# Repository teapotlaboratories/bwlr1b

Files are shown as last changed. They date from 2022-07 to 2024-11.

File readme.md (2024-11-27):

  
  
# Teapot BWLR1B
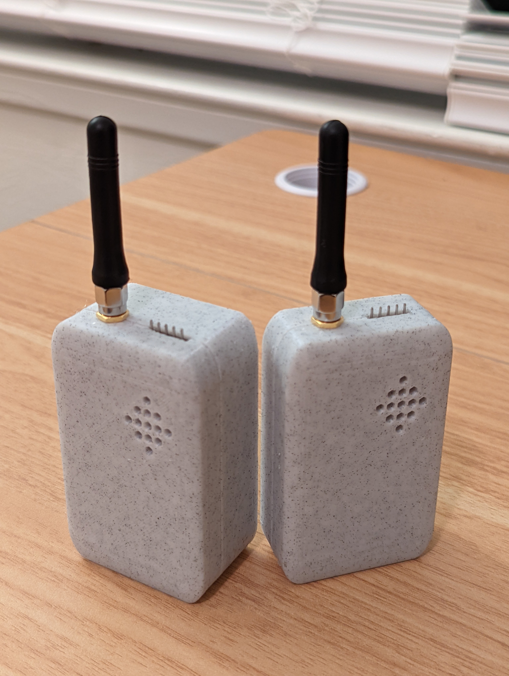
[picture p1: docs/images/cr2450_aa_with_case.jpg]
 
 
Teapot BWLR1B is a wireless LoRa environmental sensor capable of sensing temperature, humidity, air pressure and air quality using the on-board BME680. 
By using an STM32WLE MCU, the device is capable of multi-year operation before changing the batteries

Teapot BWLR1B is part of  [Teapot open-hardware project](https://github.com/teapotlaboratories). 

## Sponsorship
We sincerely thank [PCBWay](https://www.pcbway.com/) for their sponsorship and support. Their high-quality rapid-prototyping services, including PCB Board manufacturing, PCB Assembly, and 3D Printing, have been a great asset to our work.
We truly appreciate their attention to detail in helping us:
  - Identify design issues
  - Verify our BOM (Bill of Materials)
  - Verify the final product after assembly

On top of their technical expertise, their customer support has been responsive, and easy to work with.

## Disclaimer
- The 1KM+ range have not been verified yet
- The position of the BME680 sensor on the board might not be the most efficient 

## Future Works
- Change `SW4` wiring from GND to 3V3, to allow booting to STM32WLE USART Bootloader. This enable the user to flash the RAK3172 module using STM32CubeProgrammer without ST-Link.

## Specification

- [RAK3172](https://docs.rakwireless.com/Product-Categories/WisDuo/RAK3172-Module/Overview/): An STM32WLE5CC module
- 3.3V only power/pin. 
- 2uA Deep-Sleep
- BME680 for Environmental Sensing
- Switchable TX Power. 14 dBm(50mA) or 22 dBm(140mA) ( on 915MHz frequency )
- Supports LoRaWAN 1.0.3
- 1KM+ Range
- UART2 breakout for **Arduino** progamming
- SWD breakout for **Mbed OS/STM32Cube** programming
- SMA antenna connector
- **CR2450** battery holder *xor* **AA** battery holder
- Capacitor ( [optional to prolong CR2450 usage](https://www.rs-online.com/designspark/can-i-prolong-my-coin-cell-battery-life-with-a-capacitor) )

> Based-on [TI's White Paper](https://www.ti.com/lit/wp/swra349/swra349.pdf), using coin-cell to draw short high-power pulses (~40mA) is possible, but will reduce the effective capacity of the battery. The White Paper proposed a solution to increase the effective capacity
## Schematics

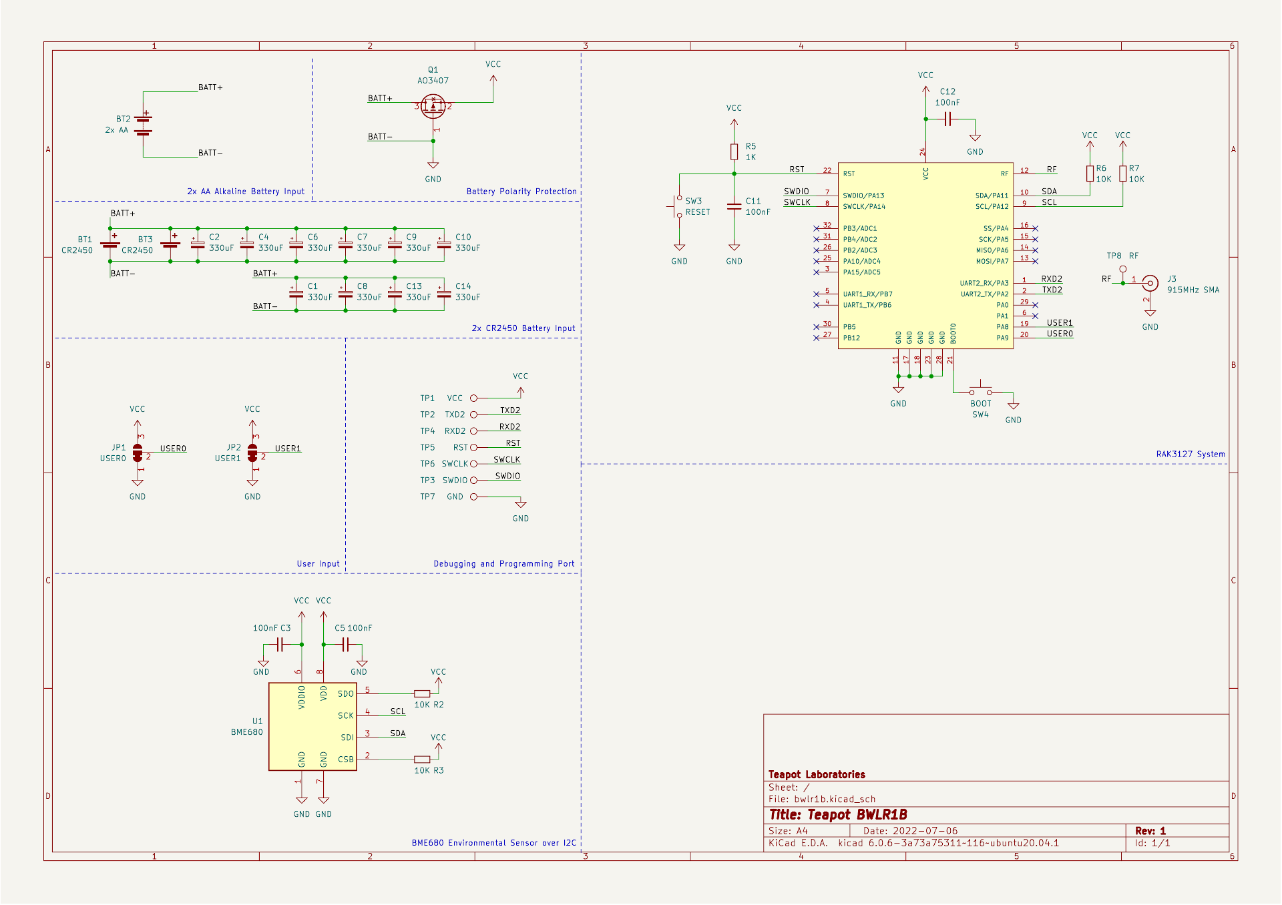
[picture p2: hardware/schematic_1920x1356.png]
schematic


## Boards 
 

Built using KiCAD v6, the board is design to be as small as possible when operated using CR2450 coin-cell batteries

### Design
The device designed to be operable using **2x CR2450** coin cell batteries *xor* the standard **2x AA** batteries.
By using the RAK3172 module, it is possible to use the IPEX [variant](https://store.rakwireless.com/products/wisduo-lpwan-module-rak3172?variant=40014759297222) of the module and use a [PCB antenna](https://store.rakwireless.com/products/pcb-antenna-for-lora) connected to the IPEX port on the RAK3172 module.
| Top Board | Bottom Board with AA or CR2450 Battery |
|--|--|
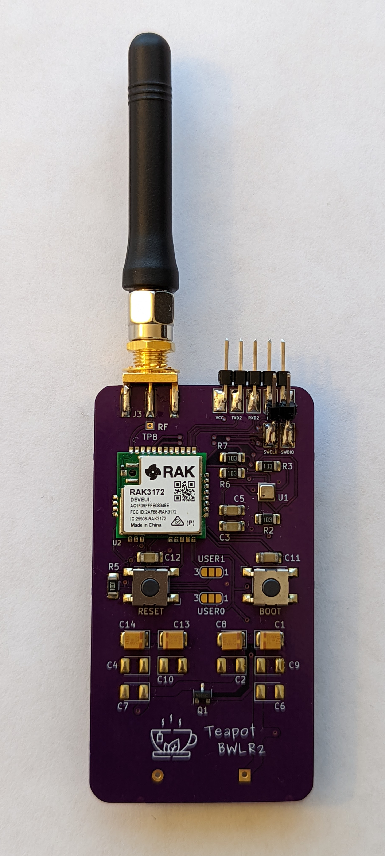
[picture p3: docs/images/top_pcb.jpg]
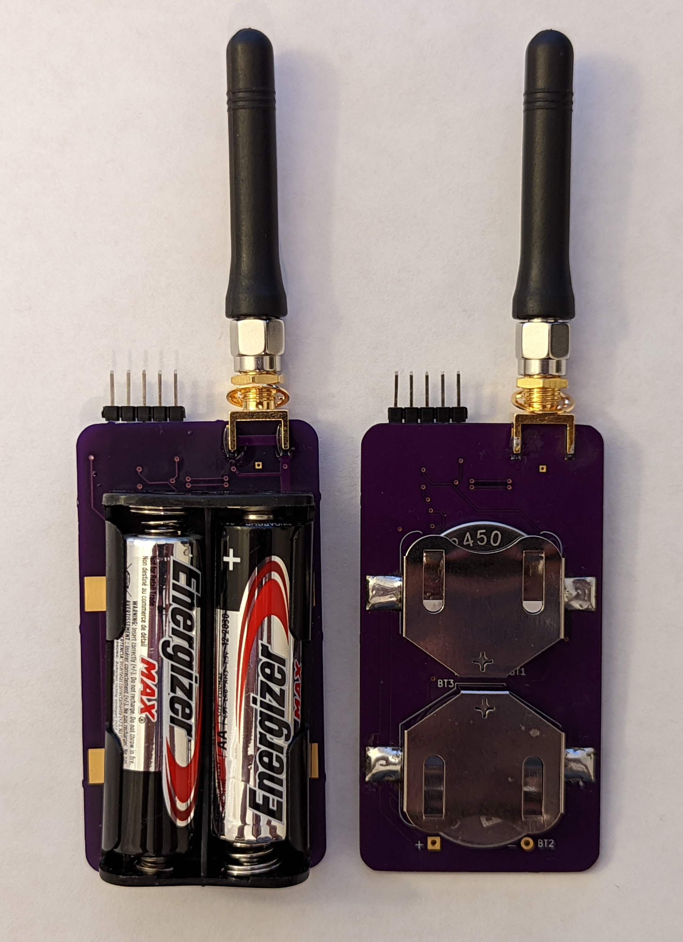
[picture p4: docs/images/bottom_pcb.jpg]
|  |  |
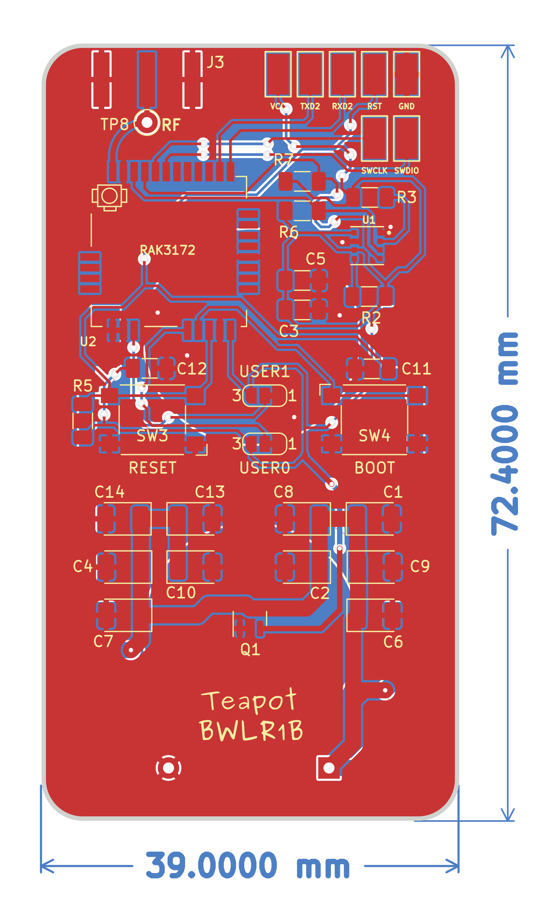
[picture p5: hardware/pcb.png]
   
  
### Case
 The cases are available for the CR2450 variant and the AA variant, 3D printable with any generic 3D printer with/without suppport (depends on the orientation). The STL files are available [here](https://github.com/teapotlaboratories/bwlr1b/tree/master/hardware/case)
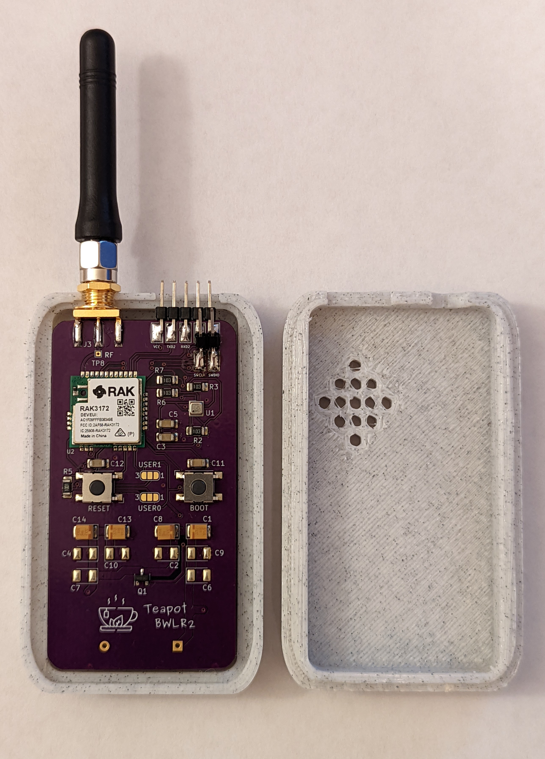
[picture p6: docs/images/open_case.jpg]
  

### Measurement
Power consumption and solar charging current are measured using [Nordic PPK2](https://www.nordicsemi.com/Products/Development-hardware/Power-Profiler-Kit-2).
The following are the summary of the measurement:
- Transmit 14dBm:  446ms @ 43mA
- Deep-Sleep : 2 uA

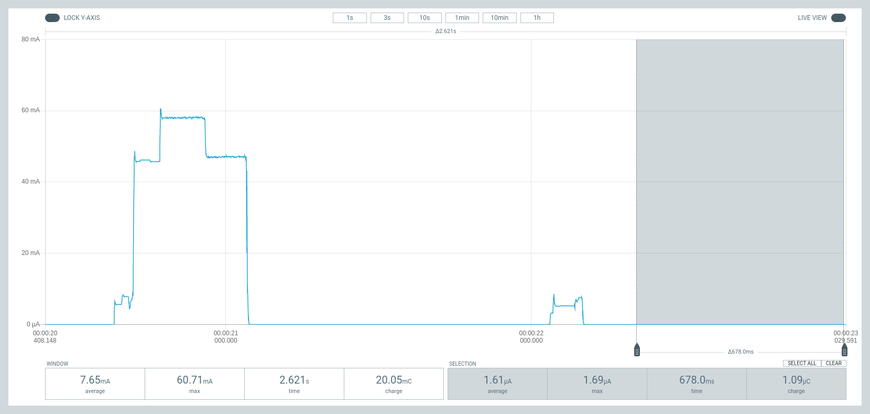
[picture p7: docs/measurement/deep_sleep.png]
deep_sleep
<p align="center"><br><b>Deep-Sleep</b></p>

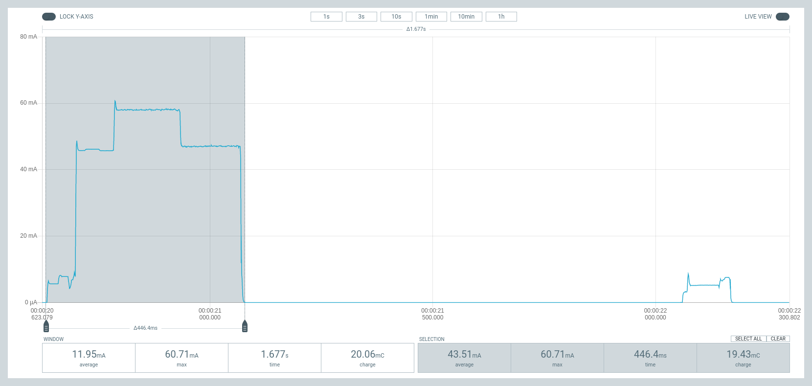
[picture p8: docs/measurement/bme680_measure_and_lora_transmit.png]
bme688_measure_and_lora_transmit
<p align="center"><br><b>BME688 Measure and LoRa Transmit</b></p>

More measurement can be found [here](https://github.com/teapotlaboratories/bwlr1b/tree/main/docs/measurement)
 
### Bill Of Materials
Most of the components are generic and can be bought from any electornics/semi-conductor distributor. RAK3172 is the only component available in [RAKwireless store.](https://store.rakwireless.com/products/wisduo-lpwan-module-rak3172?variant=40014759493830). The bill of materials can be downloaded [here](https://raw.githubusercontent.com/teapotlaboratories/bwlr1b/master/hardware/bill_of_materials.csv)

> :warning: **Be sure to buy the RAK3172 variant without IPEX to use the SMA connector** 

|Id |Designator |Package |Quantity|Designation|Supplier and ref|Notes |
|---|---|---|---|---|---|---|
|1  |BT2 |BatteryHolder_Keystone_2462_2xAA |1 |2x AA | |Mutual Exclusive with BT3 and BT1|
|2  |BT3,BT1 |BatteryHolder_Keystone_3008_1x2450 |2 |CR2450 | |Mutual Exclusive with BT2 |
|3  |C5,C12,C11,C3 |C_1206_3216Metric_Pad1.33x1.80mm_HandSolder |4 |100nF | | |
|4  |C9,C8,C10,C2,C4,C13,C14,C6,C1,C7|CP_EIA-3528-15_AVX-H_Pad1.50x2.35mm_HandSolder|10 |330uF | |Optional |
|5  |J3 |SMA_Amphenol_132289_EdgeMount |1 |915MHz SMA | | |
|6  |Q1 |SOT-23 |1 |AO3407 | | |
|7  |R5 |R_1206_3216Metric_Pad1.30x1.75mm_HandSolder |1 |1K | | |
|8  |R7,R2,R3,R6 |R_1206_3216Metric_Pad1.30x1.75mm_HandSolder |4 |10K | | |
|9  |SW3 |SW_SPST_Omron_B3FS-100xP |1 |RESET | | |
|10 |SW4 |SW_SPST_Omron_B3FS-100xP |1 |BOOT | | |
|11 |U1 |BME680-PSON80P300X300X100-8N |1 |BME680 | | |
|12 |U2 |RAK3172 without IPEX |1 |RAK3172 |RAKwireless | |

## Programming
Programming the device can be done over the **UART2** or **SWD**, available next to the SMA antenna port.
Out of the factory, the RAK3172 chip ships with an **AT firmware** that can be tested by connecting a USB-to-UART bridge to the **UART2** port.

The following are some very good tutorial to start developing with the device:

- [Communicating with the AT firmware](https://docs.rakwireless.com/Product-Categories/WisDuo/RAK3172-Module/Quickstart/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)
 - [Programming with Arduino](https://docs.rakwireless.com/Product-Categories/WisDuo/RAK3172-Module/Quickstart/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)
 - [Programming with STM32Cube](https://docs.rakwireless.com/Product-Categories/WisDuo/RAK3172-Module/Low-Level-Development/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)
 - [Programming with MbedOS](https://github.com/hallard/LoRa-E5-Tiny/blob/main/README.md#compile-and-flash-firmware)

For connecting to the **UART2** port, use any USB-to-UART bridge module. In testing, the [Sparkfun](https://www.sparkfun.com/products/14050) board is used for communication with AT firmware and programming over **Arduino**.
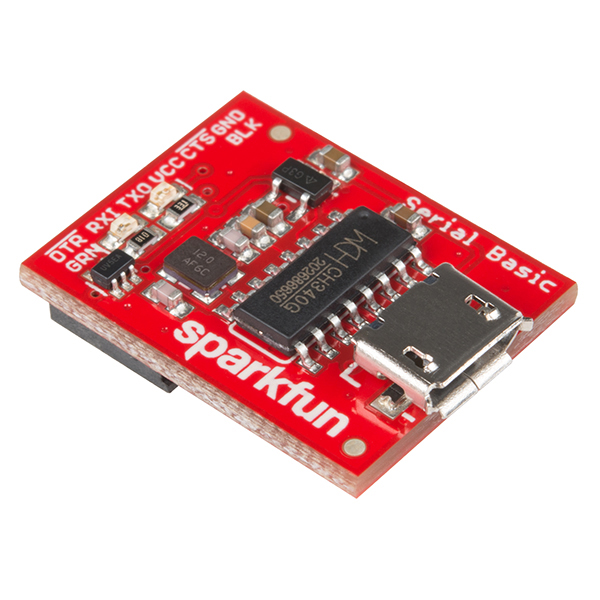
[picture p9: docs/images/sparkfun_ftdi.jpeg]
 <p align="center"> <br>Sparkfun USB-to-UART Bridge</p>

> :warning: **Be sure to only use 3.3V module. Do not 5V module** 

For connecting to the **SWD** port, use ST-Link v2  in-circuit debugger and programmer from STM. In testing, ST-Link v2 clone will not work. The ST-Link v2 should atleast be reconizeable by the [STM32CubeProgrammer](https://www.st.com/en/development-tools/stm32cubeprog.html).
A cheap and alternative way to get an authorized ST-Link is to buy a Nucleo board, cut the top part which contain the ST-Link and use it as an external programmer.
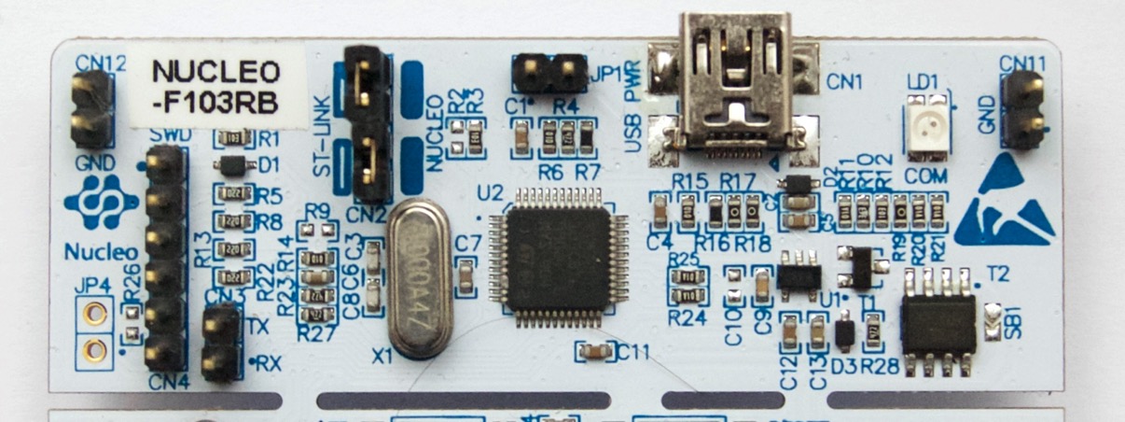
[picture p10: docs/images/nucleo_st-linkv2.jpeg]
 <p align="center"> <br>ST-Link v2 from a Nucleo Development Board</p>
Here are some good tutorial to convert a Nucleo to and external ST-Link v2:

 - https://www.radioshuttle.de/en/turtle-en/nucleo-st-link-interface-en/
 - https://jeelabs.org/book/1547a/index.html

## Reference
The project won't be possible without the amazing work from people across the globe. The following are the reference to those awesome projects:

 - [LoRa e5 Tiny](https://github.com/hallard/LoRa-E5-Tiny)
 - [AERQ - Air Quality Monitoring](https://www.seeedstudio.com/blog/2022/04/27/monitoring-indoor-air-pollutants-the-silent-issue-for-smart-city-iot-using-seeed-lora-e5-and-fusion-pcba/)

## License
The product is open-source! However, some part of library used under **src**, might have it's own license.
Please reach out or create a ticket to report any license violation.



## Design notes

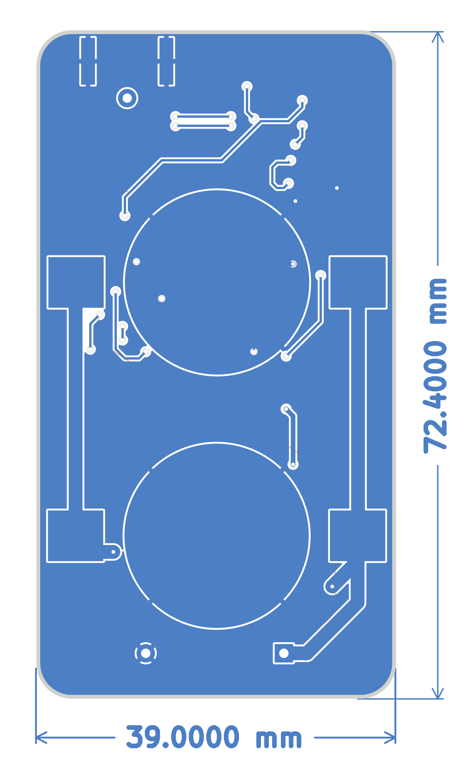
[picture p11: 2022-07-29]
hardware/pcb_bottom.png

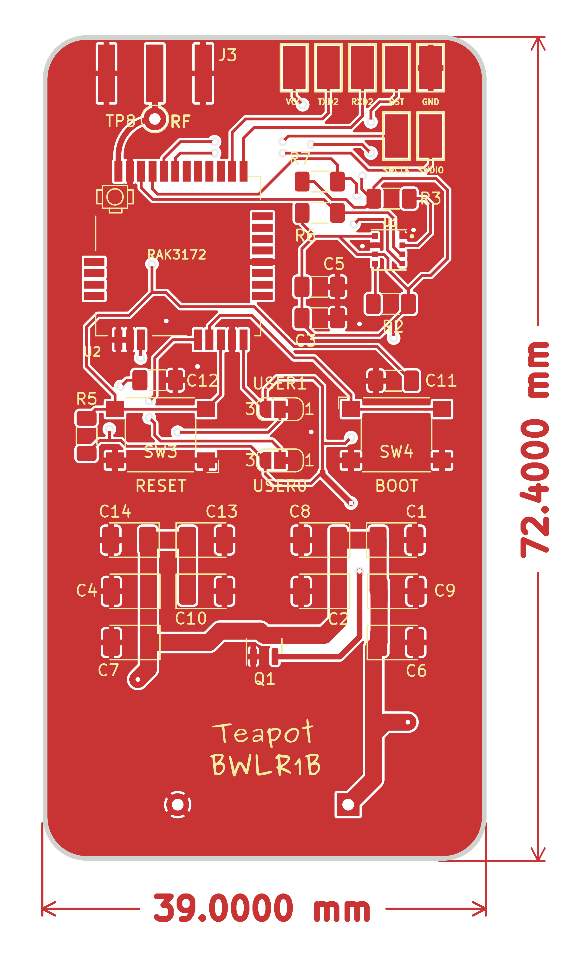
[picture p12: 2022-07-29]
hardware/pcb_top.png

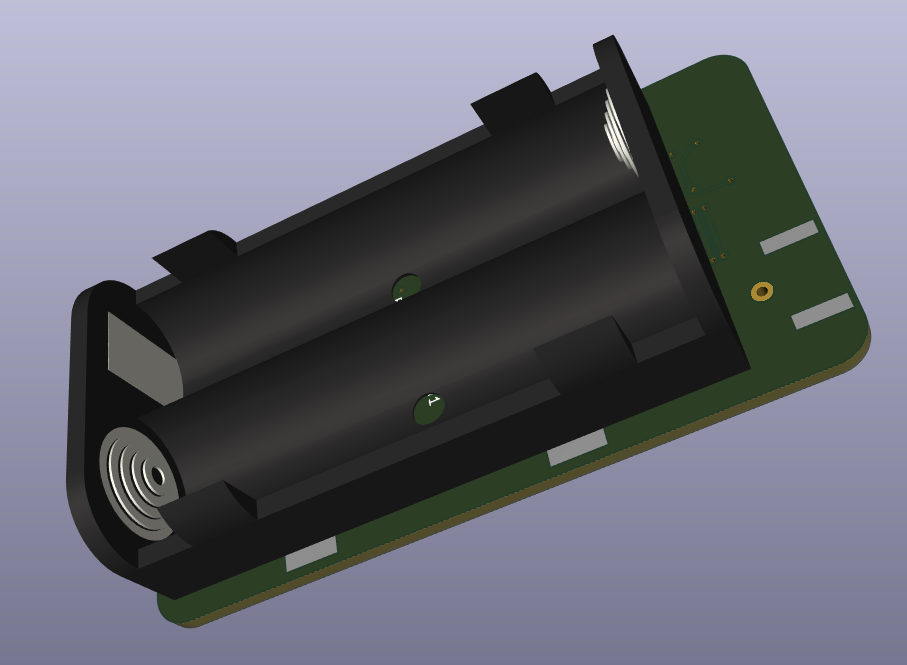
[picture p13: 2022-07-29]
docs/images/3d_bottom_aa.png

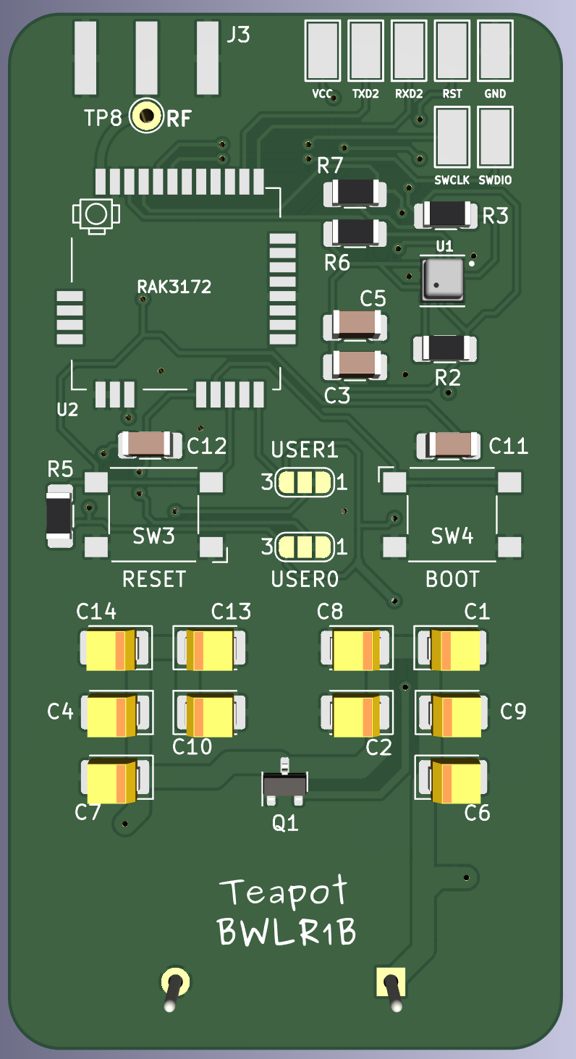
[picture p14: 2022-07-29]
docs/images/3d_top.png

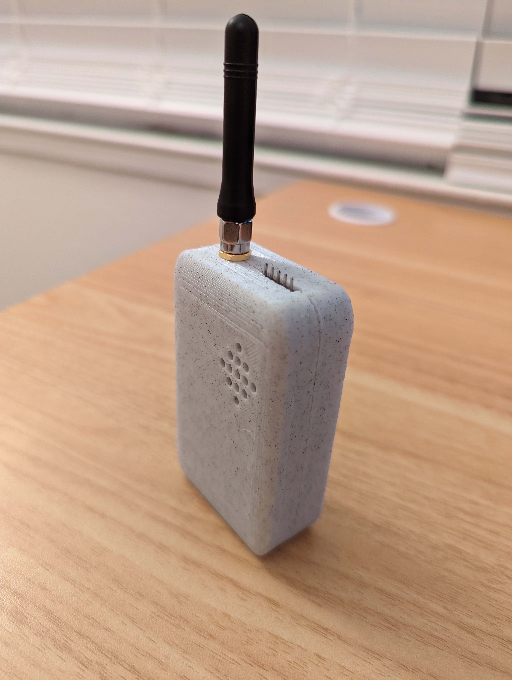
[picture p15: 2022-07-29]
docs/images/cr2450_with_case.jpg

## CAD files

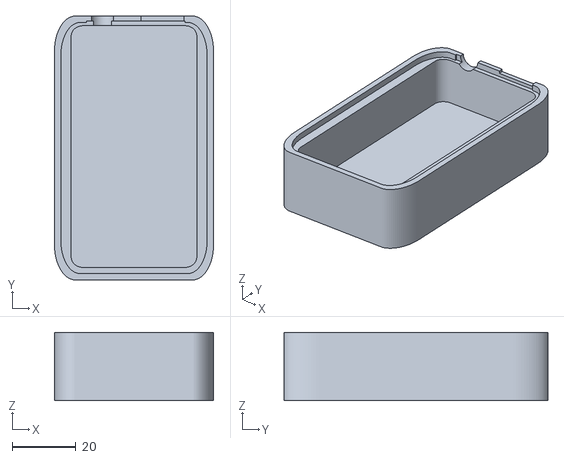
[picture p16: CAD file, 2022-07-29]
hardware/case/bottom_case_aa.stl
50.0 x 83.0 x 21.5

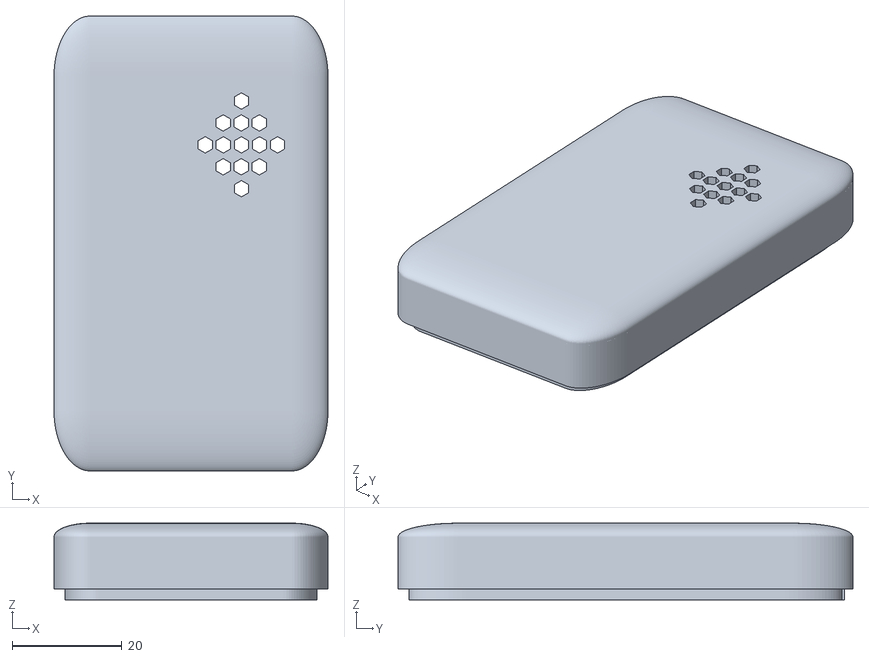
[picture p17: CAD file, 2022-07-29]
hardware/case/top_case.stl
50.0 x 83.0 x 14.0

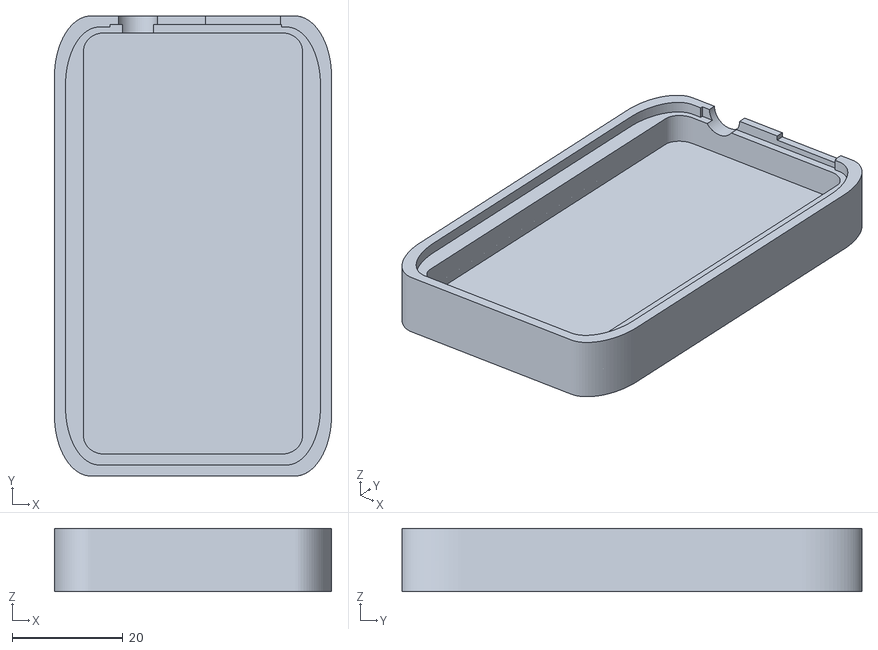
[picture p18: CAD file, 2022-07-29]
hardware/case/bottom_case_cr2450.stl
50.0 x 83.0 x 11.4

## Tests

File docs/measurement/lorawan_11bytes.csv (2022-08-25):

Timestamp(ms) | Current(uA)
0 | 1.512
1 | 1.502
2 | 1.505
3 | 1.501
4 | 1.505
5 | 1.497
6 | 1.482
7 | 1.502
8 | 1.486
9 | 1.482
10 | 1.491
11 | 1.494
12 | 1.487
13 | 1.499
14 | 1.496
15 | 1.494
16 | 1.487
17 | 1.488
18 | 1.484
19 | 1.492
20 | 1.496
21 | 1.498
22 | 1.496
23 | 1.502
24 | 1.492
25 | 1.496
26 | 1.494
27 | 1.500
28 | 1.501
29 | 1.493
30 | 1.491
31 | 1.495
32 | 1.499
33 | 1.490
34 | 1.498
35 | 1.497
36 | 1.507
37 | 1.501
38 | 1.493
39 | 1.497
40 | 1.498
41 | 1.495
42 | 1.496
43 | 1.506
44 | 1.507
45 | 1.499
46 | 1.500
47 | 1.496
48 | 1.504
49 | 1.493
50 | 1.506
51 | 1.501
52 | 1.522
53 | 1.542
54 | 1.537
55 | 1.542
56 | 1.535
57 | 1.547
58 | 1.542
59 | 1.542
60 | 1.533
61 | 1.519
62 | 1.525
63 | 1.526
64 | 1.523
65 | 1.519
66 | 1.516
67 | 1.525
68 | 1.528
69 | 1.522
70 | 1.530
71 | 1.530
72 | 1.525
73 | 1.519
74 | 1.514
75 | 1.511
76 | 1.508
77 | 1.500
78 | 1.504
79 | 1.506
80 | 1.509
81 | 1.500
82 | 1.506
83 | 1.506
84 | 1.507
85 | 1.512
86 | 1.515
87 | 1.511
88 | 1.501
89 | 1.509
90 | 1.504
91 | 1.514
92 | 1.512
93 | 1.512
94 | 1.506
95 | 1.509
96 | 1.500
97 | 1.512
98 | 1.509
99 | 1.507
100 | 1.503
101 | 1.499
102 | 1.494
103 | 1.500
104 | 1.500
105 | 1.506
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

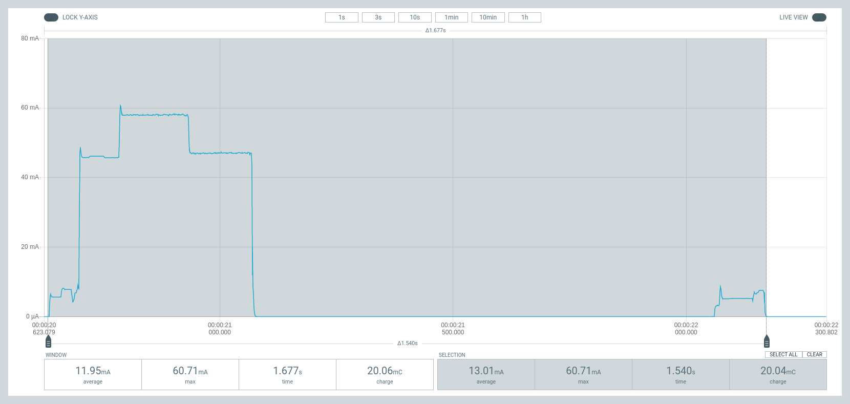
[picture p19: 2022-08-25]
docs/measurement/active.png

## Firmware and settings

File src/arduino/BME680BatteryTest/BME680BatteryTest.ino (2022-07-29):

/*! @file I2CDemo.ino

@section I2CDemo_intro_section Description

Example program for using I2C to set and read the Bosch BME680 sensor. The sensor measures
temperature, pressure and humidity and is described at
https://www.bosch-sensortec.com/bst/products/all_products/BME680. The datasheet is available from
Bosch at https://ae-bst.resource.bosch.com/media/_tech/media/datasheets/BST-BME680_DS001-11.pdf \n\n

The most recent version of the BME680 library is available at https://github.com/SV-Zanshin/BME680
and the documentation of the library as well as example programs are described in the project's wiki
pages located at https://github.com/SV-Zanshin/BME680/wiki. \n\n

The BME680 is an extremely small physical package that is so tiny as to be impossible to solder at
home, hence it will be used as part of a third-party breakout board. There are several such boards
available at this time, for example \n Company  | Link
-------  | ----------
Sparkfun | https://www.sparkfun.com/products/14570
BlueDot  | https://www.bluedot.space/sensor-boards/bme680/
Adafruit |
https://learn.adafruit.com/adafruit-BME680-humidity-barometric-pressure-temperature-sensor-breakout
\n\n

Bosch supplies sample software that runs on various platforms, including the Arduino family; this
can be downloaed at https://github.com/BoschSensortec/BSEC-Arduino-library . This software is part
of the Bosch "BSEC" (Bosch Sensortec Environmental Cluster) framework and somewhat bulky and
unwieldy for typical Arduino applications, hence the choice to make a more compact and rather less
abstract library.

This example program initializes the BME680 to use I2C for communications. The library does not
using floating point numbers to save on memory space and computation time. The values for
Temperature, Pressure and Humidity are returned in deci-units, e.g. a Temperature reading of "2731"
means "27.31" degrees Celsius. The display in the example program uses floating point for
demonstration purposes only.  Note that the temperature reading is generally higher than the ambient
temperature due to die and PCB temperature and self-heating of the element.\n\n

The pressure reading needs to be adjusted for altitude to get the adjusted pressure reading. There
are numerous sources on the internet for formulae converting from standard sea-level pressure to
altitude, see the data sheet for the BME180 on page 16 of
http://www.adafruit.com/datasheets/BST-BMP180-DS000-09.pdf. Rather than put a floating-point
function in the library which may not be used but which would use space, an example altitude
computation function has been added to this example program to show how it might be done.

@section I2CDemolicense License

This program is free software: you can redistribute it and/or modify it under the terms of the GNU
General Public License as published by the Free Software Foundation, either version 3 of the
License, or (at your option) any later version. This program is distributed in the hope that it will
be useful, but WITHOUT ANY WARRANTY; without even the implied warranty of MERCHANTABILITY or FITNESS
FOR A PARTICULAR PURPOSE.  See the GNU General Public License for more details. You should have
received a copy of the GNU General Public License along with this program.  If not, see
<http://www.gnu.org/licenses/>.

@section I2CDemoauthor Author

Written by Arnd\@SV-Zanshin

@section I2CDemoversions Changelog

Version | Date       | Developer  | Comments
------- | ---------- | ---------- | ---------------------------------------------------------------
1.0.3   | 2020-07-04 | SV-Zanshin | Issue #25 implement clang-formatting
1.0.2   | 2020-05-09 | SV-Zanshin | Issue #8  clean up comments and code
1.0.1   | 2019-01-30 | SV-Zanshin |           Removed old comments
1.0.1   | 2019-01-26 | SV-Zanshin | Issue #3  convert documentation to Doxygen
1.0.0b  | 2018-06-30 | SV-Zanshin |           Cloned from original BME280 program
*/
#include "Zanshin_BME680.h"  // Include the BME680 Sensor library
/**************************************************************************************************
** Declare all program constants                                                                 **
**************************************************************************************************/
const uint32_t SERIAL_SPEED{115200};  ///< Set the baud rate for Serial I/O

/**************************************************************************************************
** Declare global variables and instantiate classes                                              **
**************************************************************************************************/
BME680_Class BME680;  ///< Create an instance of the BME680 class
///< Forward function declaration with default value for sea level
float altitude(const int32_t press, const float seaLevel = 1013.25);
float altitude(const int32_t press, const float seaLevel) {
  /*!
  @brief     This converts a pressure measurement into a height in meters
  @details   The corrected sea-level pressure can be passed into the function if it is known,
             otherwise the standard atmospheric pressure of 1013.25hPa is used (see
             https://en.wikipedia.org/wiki/Atmospheric_pressure) for details.
  @param[in] press    Pressure reading from BME680
  @param[in] seaLevel Sea-Level pressure in millibars
  @return    floating point altitude in meters.
  */
  static float Altitude;
  Altitude =
      44330.0 * (1.0 - pow(((float)press / 100.0) / seaLevel, 0.1903));  // Convert into meters
  return (Altitude);
}  // of method altitude()

void setup() {
  /*!
  @brief    Arduino method called once at startup to initialize the system
  @details  This is an Arduino IDE method which is called first upon boot or restart. It is only
            called one time and then control goes to the main "loop()" method, from which
            control never returns
  @return   void
  */
  Serial.begin(SERIAL_SPEED);  // Start serial port at Baud rate
#ifdef __AVR_ATmega32U4__      // If this is a 32U4 processor, then wait 3 seconds to init USB port
  delay(3000);
#endif
  Serial.print(F("Starting I2CDemo example program for BME680\n"));
  Serial.print(F("- Initializing BME680 sensor\n"));
  while (!BME680.begin(I2C_STANDARD_MODE)) {  // Start BME680 using I2C, use first device found
    Serial.print(F("-  Unable to find BME680. Trying again in 5 seconds.\n"));
    delay(5000);
  }  // of loop until device is located
  Serial.print(F("- Setting 16x oversampling for all sensors\n"));
  BME680.setOversampling(TemperatureSensor, Oversample16);  // Use enumerated type values
  BME680.setOversampling(HumiditySensor, Oversample16);     // Use enumerated type values
  BME680.setOversampling(PressureSensor, Oversample16);     // Use enumerated type values
  Serial.print(F("- Setting IIR filter to a value of 4 samples\n"));
  BME680.setIIRFilter(IIR4);  // Use enumerated type values
  Serial.print(F("- Setting gas measurement to 320\xC2\xB0\x43 for 150ms\n"));  // "�C" symbols
  BME680.setGas(320, 150);  // 320�c for 150 milliseconds
}  // of method setup()
void loop() {
  /*!
  @brief    Arduino method for the main program loop
  @details  This is the main program for the Arduino IDE, it is an infinite loop and keeps on
            repeating. The "sprintf()" function is to pretty-print the values, since floating
            point is not supported on the Arduino, split the values into those before and those
            after the decimal point.
  @return   void
  */
  static int32_t  temp, humidity, pressure, gas;  // BME readings
  static char     buf[16];                        // sprintf text buffer
  static float    alt;                            // Temporary variable
  static uint16_t loopCounter = 0;                // Display iterations
  if (loopCounter % 25 == 0) {                    // Show header @25 loops
    Serial.print(F("\nLoop Temp\xC2\xB0\x43 Humid% Press hPa   Alt m Air m"));
    Serial.print(F("\xE2\x84\xA6 Battery V\n==== ====== ====== ========= ======= ====== =========\n"));  // "�C" symbol
  }                                                     // if-then time to show headers
  BME680.getSensorData(temp, humidity, pressure, gas);  // Get readings
  if (loopCounter++ != 0) {                             // Ignore first reading, might be incorrect
    sprintf(buf, "%4d %3d.%02d", (loopCounter - 1) % 9999,  // Clamp to 9999,
            (int8_t)(temp / 100), (uint8_t)(temp % 100));   // Temp in decidegrees
    Serial.print(buf);
    sprintf(buf, "%3d.%03d", (int8_t)(humidity / 1000),
            (uint16_t)(humidity % 1000));  // Humidity milli-pct
    Serial.print(buf);
    sprintf(buf, "%7d.%02d", (int16_t)(pressure / 100),
            (uint8_t)(pressure % 100));  // Pressure Pascals
    Serial.print(buf);
    alt = altitude(pressure);                                                // temp altitude
    sprintf(buf, "%5d.%02d", (int16_t)(alt), ((uint8_t)(alt * 100) % 100));  // Altitude meters
    Serial.print(buf);
    sprintf(buf, "%4d.%02d", (int16_t)(gas / 100), (uint8_t)(gas % 100));  // Resistance milliohms
    Serial.print(buf);
    sprintf(buf, " %.3f\n", api.system.bat.get());  // Resistance milliohms
    Serial.print(buf);
    
    //api.system.sleep.all(10000);
    delay(1000);  // Wait 10s
  }                // of ignore first reading
}  // of method loop()

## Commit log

2022-07-29 initial release
    [bill_of_materials.csv, bottom_case_aa.stl, bottom_case_cr2450.stl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]
2022-07-29 add programmer board pictures
2022-07-29 update BoM
    [bill_of_materials.csv]
2022-07-29 add teapot's kicad library
2022-08-25 update logo
    [bwlr1b.kicad_pcb]
2022-08-25 add measurement result
    [lorawan_11bytes.csv]
2022-09-03 update footprint
    [bwlr1b.kicad_pcb]

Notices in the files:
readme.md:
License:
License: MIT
